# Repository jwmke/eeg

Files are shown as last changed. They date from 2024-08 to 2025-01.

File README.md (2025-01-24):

# Open-Source Affordable EEG PCB

### An 8-channel EEG Pi Pico W shield, based off of OpenBCI's [Cyton Biosensing Board](https://shop.openbci.com/products/cyton-biosensing-board-8-channel), for 1/10th the price.



The heart of this PCB is a Texas Instrument's [ADS1299](https://www.ti.com/product/ADS1299), a low noise, 8-Channel, Analog-to-Digital Converter.

## Instructions
1. Update your SSID and PASSWORD in the pico/main.py file
2. Upload the main.py to the Pi Pico W
3. Run the pico/main.py on the Pico Pi W and note the printed IP
5. Unplug the Pi Pico W from the PC and place it into the PCB
6. Update the PICO_IP in the computer/plot_data.py file
7. Run the computer/plot_data.py on a PC
8. Plug a 3.7V Lipo battery into the PCB
9. Blinking LED == Connecting, Solid LED == Succesfully streaming to PC

## Schematics





















## Layout

Top



Bottom



Ground



AVSS/-2.5V



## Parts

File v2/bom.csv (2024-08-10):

Id | Designator | Footprint | Quantity | Designation | Supplier and ref
1 | C22,C19,C18,C3 | C_0603_1608Metric_Pad1.08x0.95mm_HandSolder | 4 | 10µF
2 | R9,R7,R8,R3,R10,R6,R2 | R_0603_1608Metric_Pad0.98x0.95mm_HandSolder | 7 | 10kΩ
3 | U11 | 73225 | 1 | TPS73225DBVR
4 | U9,U4,U3 | tpd4e1b06dckr | 3 | TPD4E1B06DCKR
5 | U8 | 72325 | 1 | TPS72325DBVT
6 | U7 | 73233 | 1 | TPS73233DBVT
7 | U6 | SOTFL50P160X60-6N | 1 | TPS61023DRLR
8 | U5 | lm266 | 1 | LM2664M6
9 | RN8,RN7,RN6,RN5 | RES-ARRAY-SMD_0603-8P-L3.2-W1.6-BL | 4 | CAY16-103J4LF
10 | R5 | R_0603_1608Metric_Pad0.98x0.95mm_HandSolder | 1 | 100kΩ
11 | R4 | R_0603_1608Metric_Pad0.98x0.95mm_HandSolder | 1 | 732kΩ
12 | R1 | R_0603_1608Metric_Pad0.98x0.95mm_HandSolder | 1 | 1MΩ
13 | L1 | IND_74438357010_WRE | 1 | 1µH
14 | J1 | JST_PH_B2B-PH-K_1x02_P2.00mm_Vertical | 1 | Conn_01x02_Pin
15 | C30,C28,C23 | C_0603_1608Metric_Pad1.08x0.95mm_HandSolder | 3 | 0.01µF
16 | C29,C27,C17,C14,C10,C4,C12,C5,C9 | C_0603_1608Metric_Pad1.08x0.95mm_HandSolder | 9 | 1µF
17 | C24,C21,C20 | C_0603_1608Metric_Pad1.08x0.95mm_HandSolder | 3 | 22µF
18 | C16,C15,C11,C6,C2,C8 | C_0603_1608Metric_Pad1.08x0.95mm_HandSolder | 6 | 0.1µF
19 | C7 | C_0603_1608Metric_Pad1.08x0.95mm_HandSolder | 1 | 1nF
20 | C1 | C_0603_1608Metric_Pad1.08x0.95mm_HandSolder | 1 | 1.5nF
21 | CN4,CN3,CN2,CN1 | CAP-ARRAY-SMD_6124-8P-L3.2-W1.6-BL | 4 | W2A41C681KAT2A
22 | J3,J4 | PinSocket_1x20_P2.54mm_Vertical | 2 | Conn_01x20_Socket
23 | J2 | PinHeader_1x09_P2.54mm_Vertical | 1 | Conn_01x09_Pin
24 | U1 | PAG64_TEX | 1 | ADS1299IPAGR
25 | C13 | C_1206_3216Metric_Pad1.33x1.80mm_HandSolder | 1 | 100µF

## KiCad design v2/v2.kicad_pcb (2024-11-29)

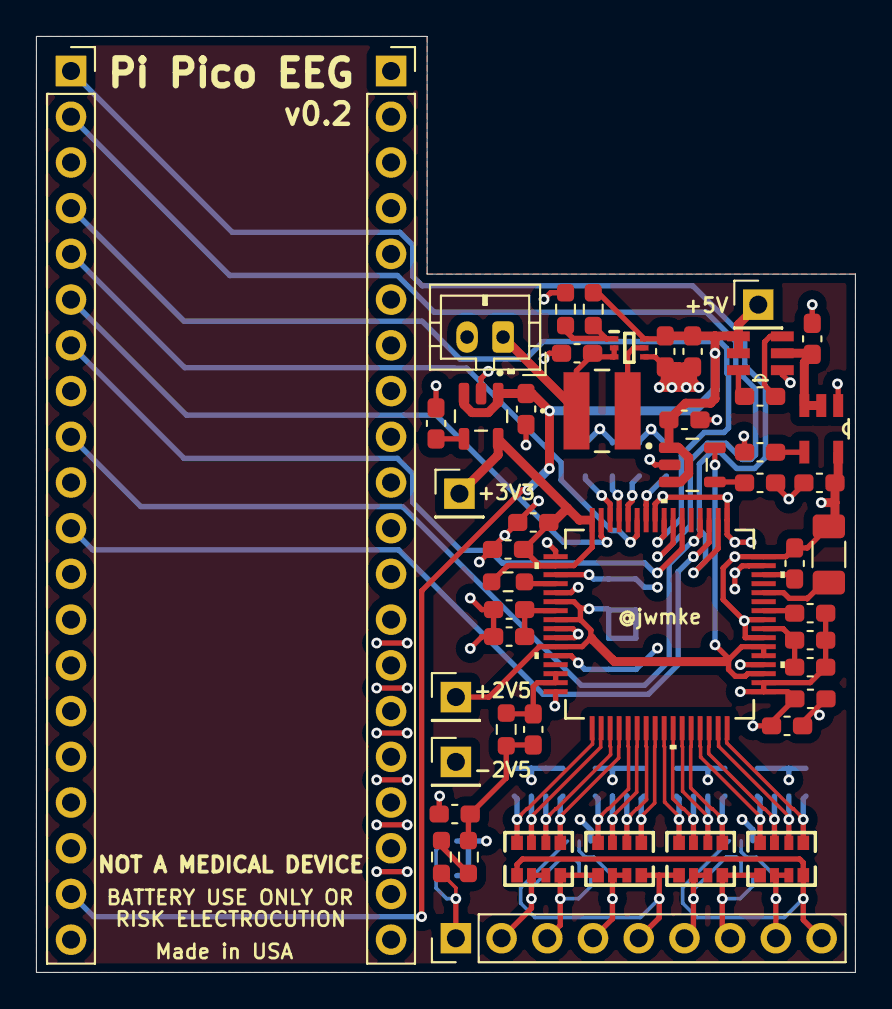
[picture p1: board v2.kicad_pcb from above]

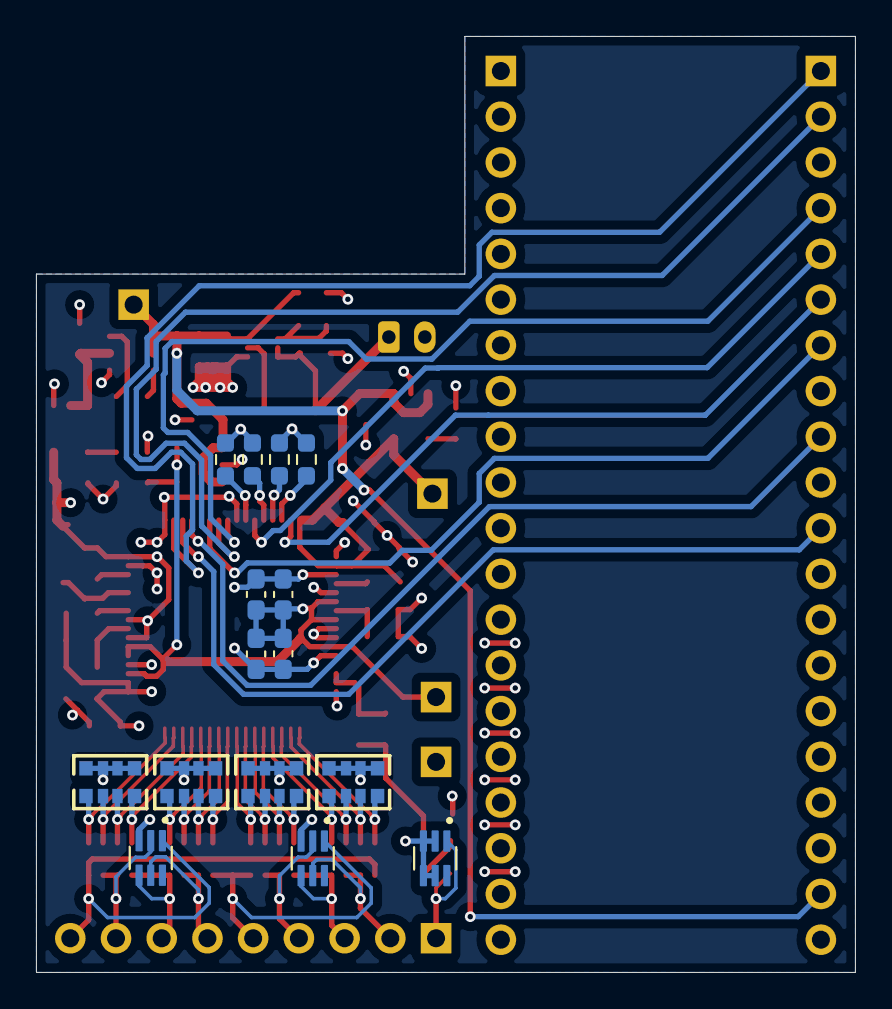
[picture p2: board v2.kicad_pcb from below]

Board: 4 copper layers, 45.5 x 52.0 mm, 64 parts (15 on the bottom side), 60 nets.

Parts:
C1: 1.5nF; C_0603_1608Metric_Pad1.08x0.95mm_HandSolder
C2, C6, C8, C11, C15, C16: 0.1µF; C_0603_1608Metric_Pad1.08x0.95mm_HandSolder
C3, C18, C19, C22: 10µF; C_0603_1608Metric_Pad1.08x0.95mm_HandSolder
C4, C5, C9, C10, C12, C14, C17, C27, C29: 1µF; C_0603_1608Metric_Pad1.08x0.95mm_HandSolder
C7: 1nF; C_0603_1608Metric_Pad1.08x0.95mm_HandSolder
C13: 100µF; C_1206_3216Metric_Pad1.33x1.80mm_HandSolder
C20, C21, C24: 22µF; C_0603_1608Metric_Pad1.08x0.95mm_HandSolder
C23, C28, C30: 0.01µF; C_0603_1608Metric_Pad1.08x0.95mm_HandSolder
CN1, CN2, CN3, CN4: W2A41C681KAT2A; CAP-ARRAY-SMD_6124-8P-L3.2-W1.6-BL
J1: Conn_01x02_Pin; JST_PH_B2B-PH-K_1x02_P2.00mm_Vertical
J2: Conn_01x09_Pin; PinHeader_1x09_P2.54mm_Vertical
J3, J4: Conn_01x20_Socket; PinSocket_1x20_P2.54mm_Vertical
J5, J6, J7, J8: Conn_01x01_Pin; PinHeader_1x01_P2.54mm_Vertical
L1: 1µH; IND_74438357010_WRE
R1: 1MΩ; R_0603_1608Metric_Pad0.98x0.95mm_HandSolder
R2, R3, R6, R7, R8, R9, R10: 10kΩ; R_0603_1608Metric_Pad0.98x0.95mm_HandSolder
R4: 732kΩ; R_0603_1608Metric_Pad0.98x0.95mm_HandSolder
R5: 100kΩ; R_0603_1608Metric_Pad0.98x0.95mm_HandSolder
RN5, RN6, RN7, RN8: CAY16-103J4LF; RES-ARRAY-SMD_0603-8P-L3.2-W1.6-BL
U1: ADS1299IPAGR; PAG64_TEX
U3, U4, U9: TPD4E1B06DCKR; tpd4e1b06dckr
U5: LM2664M6; lm266
U6: TPS61023DRLR; SOTFL50P160X60-6N
U7: TPS73233DBVT; 73233
U8: TPS72325DBVT; 72325
U11: TPS73225DBVR; 73225

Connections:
+2V5: C4.1, C6.1, C10.1, C11.1, J8.1, U1.19 (AVDD), U1.21 (AVDD), U1.22 (AVDD), U1.54 (AVDD1), U1.56 (AVDD), U1.59 (AVDD), U11.5 (OUT)
+3V3: C16.1, C17.1, J7.1, R6.1, U1.48 (DVDD), U1.50 (DVDD), U7.5 (OUT)
+5V: C20.2, C21.2, C27.2, C29.2, J3.19, J5.1, R4.1, U5.4 (~SD), U5.5 (V+), U6.6 (VOUT), U7.1 (IN), U7.3 (EN), U11.1 (IN), U11.3 (EN)
-2V5: C2.1, C3.2, C5.2, C8.1, C9.1, C10.2, C11.2, C12.2, C13.2, C14.1, C15.1, C24.2, J6.1, U1.17 (SRB1), U1.18 (SRB2), U1.20 (AVSS), U1.23 (AVSS), U1.25 (VREFN), U1.32 (AVSS), U1.53 (AVSS1), U1.57 (AVSS), U1.58 (AVSS), U1.60 (BIASREF), U8.5 (OUT)
-5V: C22.2, U5.2 (OUT), U8.2 (IN), U8.3 (EN)
/ADS1299/BI: J2.1, R2.2, U9.1 (IO1)
/ADS1299/Bias: C1.2, C7.1, R1.2, R10.1
/ADS1299/CS: J3.2, U1.39 (*CS)
/ADS1299/DRDY: J3.6, U1.47 (*DRDY)
/ADS1299/I1: J2.9, RN5.1, RN8.4, U3.1 (IO1)
/ADS1299/I2: J2.8, RN8.2, RN8.3, U3.2 (IO2)
/ADS1299/I3: J2.7, RN7.4, RN8.1, U3.4 (IO3)
/ADS1299/I4: J2.6, RN7.2, RN7.3, U3.5 (IO4)
/ADS1299/I5: J2.5, RN6.4, RN7.1, U4.1 (IO1)
/ADS1299/I6: J2.4, RN6.2, RN6.3, U4.2 (IO2)
/ADS1299/I7: J2.3, RN5.4, RN6.1, U4.4 (IO3)
/ADS1299/I8: J2.2, RN5.2, RN5.3, U4.5 (IO4)
/ADS1299/IN1N: CN1.2, RN8.6, U1.15 (IN1N)
/ADS1299/IN1P: CN1.1, RN8.5, U1.16 (IN1P)
/ADS1299/IN2N: CN1.4, RN8.8, U1.13 (IN2N)
/ADS1299/IN2P: CN1.3, RN8.7, U1.14 (IN2P)
/ADS1299/IN3N: CN2.2, RN7.6, U1.11 (IN3N)
/ADS1299/IN3P: CN2.1, RN7.5, U1.12 (IN3P)
/ADS1299/IN4N: CN2.4, RN7.8, U1.9 (IN4N)
/ADS1299/IN4P: CN2.3, RN7.7, U1.10 (IN4P)
/ADS1299/IN5N: CN3.2, RN6.6, U1.7 (IN5N)
/ADS1299/IN5P: CN3.1, RN6.5, U1.8 (IN5P)
/ADS1299/IN6N: CN3.4, RN6.8, U1.5 (IN6N)
/ADS1299/IN6P: CN3.3, RN6.7, U1.6 (IN6P)
/ADS1299/IN7N: CN4.2, RN5.6, U1.3 (IN7N)
/ADS1299/IN7P: CN4.1, RN5.5, U1.4 (IN7P)
/ADS1299/IN8N: CN4.4, RN5.8, U1.1 (IN8N)
/ADS1299/IN8P: CN4.3, RN5.7, U1.2 (IN8P)
/ADS1299/MISO: J3.5, U1.43 (DOUT)
/ADS1299/MOSI: J3.1, U1.34 (DIN)
/ADS1299/PDWN: J3.11, U1.35 (*PWDN)
/ADS1299/RESET: J3.9, U1.36 (*RESET)
/ADS1299/SCLK: J3.4, U1.40 (SCLK)
/ADS1299/START: J3.7, U1.38 (START)
/Booster/VBATT: C19.1, J1.1, L1.1, U6.2 (EN), U6.3 (VIN)
GND: C4.2, C6.2, C7.2, C14.2, C15.2, C16.2, C17.2, C19.2, C20.1, C21.1, C22.1, C23.1, C24.1, C27.1, C28.1, C29.1, C30.1, CN1.5, CN1.6, CN1.7, CN1.8, CN2.5, CN2.6, CN2.7, CN2.8, CN3.5, CN3.6, CN3.7, CN3.8, CN4.5, CN4.6, CN4.7, CN4.8, J1.2, J3.18, R3.2, R5.2, R7.2, R8.2, R9.2, U1.31 (RESV1), U1.33 (DGND), U1.41 (DAISY_IN), U1.49 (DGND), U1.51 (DGND), U1.64 (RESERVED), U3.3 (GND), U4.3 (GND), U5.1 (GND), U6.4 (GND), U7.2 (GND), U8.1 (GND), U9.2 (IO2), U9.3 (GND), U9.4 (IO3), U9.5 (IO4), U11.2 (GND)
unnamed: R2.1, R10.2
unnamed: C1.1, R1.1, U1.62 (BIASIN), U1.63 (BIASOUT)
unnamed: R6.2, U1.52 (CLKSEL)
unnamed: R3.1, U1.42 (GPIO1)
unnamed: R7.1, U1.44 (GPIO2)
unnamed: R8.1, U1.45 (GPIO3)
unnamed: R9.1, U1.46 (GPIO4)
unnamed: C13.1, U1.28 (VCAP1)
unnamed: C12.1, U1.30 (VCAP2)
unnamed: C8.2, C9.2, U1.55 (VCAP3)
unnamed: C5.1, U1.26 (VCAP4)
unnamed: C2.2, C3.1, U1.24 (VREFP)
unnamed: C18.1, U5.6 (CAP+)
unnamed: C18.2, U5.3 (CAP-)
unnamed: R4.2, R5.1, U6.1 (FB)
unnamed: L1.2, U6.5 (SW)
unnamed: C28.2, U7.4 (NR/FB)
unnamed: C23.2, U8.4 (NR)
unnamed: C30.2, U11.4 (NR/FB)

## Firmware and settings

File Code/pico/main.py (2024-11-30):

import network
import socket
from machine import Pin, SPI
import time
import json

# WiFi credentials
SSID = ''
PASSWORD = ''

# Setup LED
try:
    led = Pin("LED", Pin.OUT)
except:
    led = Pin(25, Pin.OUT)

def blink_led():
    """Toggle LED state"""
    led.toggle()

def set_led_on():
    """Turn LED on solid"""
    led.value(1)

def set_led_off():
    """Turn LED off"""
    led.value(0)

def connect_wifi():
    """Connect to WiFi"""
    wlan = network.WLAN(network.STA_IF)
    wlan.active(True)
    wlan.connect(SSID, PASSWORD)
    
    # Wait for connection, blinking LED while trying
    max_wait = 10
    while max_wait > 0:
        if wlan.status() < 0 or wlan.status() >= 3:
            break
        max_wait -= 1
        print('Waiting for connection...')
        blink_led()
        time.sleep(0.5)
        blink_led()
        time.sleep(0.5)
    
    if wlan.status() != 3:
        # Connection failed - keep LED blinking
        raise RuntimeError('WiFi connection failed')
    else:
        # Connection successful - LED solid
        set_led_on()
        print('Connected')
        status = wlan.ifconfig()
        print('IP:', status[0])
    return status[0]  # Return IP address

class SoftSPI:
    def __init__(self, sck, mosi, miso, baudrate=1000000):
        self.sck = sck
        self.sck.init(Pin.OUT, value=0)
        
        self.mosi = mosi
        self.mosi.init(Pin.OUT, value=0)
        
        self.miso = miso
        self.miso.init(Pin.IN)
        
        # SPI Mode 1: CPOL=0, CPHA=1
        self.sck.value(0)  # Ensure clock starts low

    def write(self, data):
        for b in data:
            # Delay before byte transmission
            time.sleep_us(10)
            
            for i in range(8):
                self.mosi.value((b >> (7-i)) & 1)  # Set data
                time.sleep_us(5)  # Setup time
                self.sck.value(1)  # Clock high
                time.sleep_us(5)  # Hold time
                self.sck.value(0)  # Clock low
                time.sleep_us(5)  # Inter-bit delay
            
            # Inter-byte delay
            time.sleep_us(10)

    def readinto(self, buf):
        for i in range(len(buf)):
            byte = 0
            # Delay before byte reception
            time.sleep_us(10)
            
            for j in range(8):
                self.sck.value(1)  # Clock high
                time.sleep_us(5)   # Setup time
                bit = self.miso.value()
                byte = (byte << 1) | bit
                time.sleep_us(5)   # Hold time
                self.sck.value(0)  # Clock low
                time.sleep_us(5)   # Inter-bit delay
            
            buf[i] = byte
            # Inter-byte delay
            time.sleep_us(10)

class ADS1299:
    def __init__(self):
        # GPIO setup with forced output mode
        self.cs = Pin(2, Pin.OUT)    
        self.cs.on()  # Set high (inactive)
        
        self.start = Pin(7, Pin.OUT)
        self.start.off()  # Start low
        
        self.reset = Pin(9, Pin.OUT)
        self.reset.on()   # Start high
        
        self.pwdn = Pin(11, Pin.OUT)
        self.pwdn.on()    # Start high (powered on)
        
        self.drdy = Pin(6, Pin.IN)   # DRDY as input

        # Setup SPI pins with forced values
        self.sck = Pin(4, Pin.OUT)
        self.mosi = Pin(1, Pin.OUT)
        self.miso = Pin(5, Pin.IN)
        
        # Force initial states
        self.sck.off()    # Clock starts low
        self.mosi.off()   # MOSI starts low
        
        # Initialize Software SPI
        self.spi = SoftSPI(sck=self.sck, mosi=self.mosi, miso=self.miso)

            
    def write_reg(self, reg, data):
        """Write data to a register"""
        print(f"Writing register {hex(reg)} with value {hex(data)}")
        self.cs.value(1)
        time.sleep_ms(1)  # Longer delay
        self.cs.value(0)
        time.sleep_ms(1)  # Longer delay
        
        # Send write command
        self.spi.write(bytes([0x40 | reg]))
        time.sleep_ms(1)  # Longer delay
        
        # Send number of registers to write minus 1
        self.spi.write(bytes([0x00]))
        time.sleep_ms(1)  # Longer delay
        
        # Send data
        self.spi.write(bytes([data]))
        time.sleep_ms(1)  # Longer delay
        
        self.cs.value(1)
        time.sleep_ms(1)  # Longer delay

    def read_reg(self, reg):
        """Read from a register"""
        self.cs.value(1)  # Ensure CS is high initially
        time.sleep_us(2)
        self.cs.value(0)  # Pull CS low to start transaction
        time.sleep_us(2)
        self.spi.write(bytes([0x20 | reg]))  # Read command
        time.sleep_us(2)
        self.spi.write(bytes([0x00]))        # Number of registers to read
        time.sleep_us(2)
        result = bytearray(1)
        self.spi.readinto(result)
        time.sleep_us(2)
        self.cs.value(1)  # Pull CS high to end transaction
        time.sleep_us(2)
        return result[0]

    def send_command(self, cmd):
        """Send a command to ADS1299"""
        self.cs.value(1)  # Ensure CS is high initially
        time.sleep_us(2)
        self.cs.value(0)  # Pull CS low to start transaction
        time.sleep_us(2)
        self.spi.write(bytes([cmd]))
        time.sleep_us(2)
        self.cs.value(1)  # Pull CS high to end transaction
        time.sleep_us(2)
    
    def verify_communication(self):
        """Verify SPI communication"""
        print("Verifying SPI communication...")
        
        # Write a test pattern to CONFIG2 register
        test_value = 0xD0  # A value we haven't used yet
        print(f"Writing test value {hex(test_value)} to CONFIG2")
        self.write_reg(0x02, test_value)
        
        # Read back the value
        time.sleep_ms(10)
        readback = self.read_reg(0x02)
        print(f"Read back value: {hex(readback)}")
        
        if readback == test_value:
            print("SPI communication verified!")
            return True
        else:
            print("SPI communication failed!")
            return False

    def init_device(self):
        """Initialize the ADS1299"""
        print("Starting device initialization...")
        
        # Power up sequence
        print("Power down")
        self.pwdn.value(0)
        time.sleep_ms(100)
        print("Power up")
        self.pwdn.value(1)
        time.sleep_ms(100)
        
        # Reset sequence
        print("Start reset sequence")
        self.reset.value(1)
        time.sleep_ms(100)
        print("Reset low")
        self.reset.value(0)
        time.sleep_ms(100)
        print("Reset high")
        self.reset.value(1)
        time.sleep_ms(100)
        
        # Send SDATAC command
        print("Sending SDATAC command")
        self.send_command(0x11)
        time.sleep_ms(10)
        
        # Verify communication
        if not self.verify_communication():
            raise RuntimeError("Failed to establish SPI communication")
        
    def start_acquisition(self, sock):
        """Start continuous data acquisition and send over WiFi"""
        self.send_command(0x10)  # RDATAC
        self.start.value(1)
        
        try:
            while True:
                data = self.read_data_sample()
                # Convert data to JSON string
                data_json = json.dumps({'channels': data})
                sock.send(data_json.encode() + b'\n')
                time.sleep_ms(4)  # Maintain ~250 SPS
                
        except Exception as e:
            print(f"Error: {e}")
            self.start.value(0)
            self.send_command(0x11)  # SDATAC
            # If connection is lost, start blinking LED
            while True:
                blink_led()
                time.sleep(0.5)
    
    def read_data_sample(self):
        """Read one sample from all channels"""
        while self.drdy.value():
            pass
            
        self.cs.value(0)
        
        # Read 27 bytes (status + 8 channels)
        raw_data = bytearray(27)
        self.spi.readinto(raw_data)
        
        self.cs.value(1)
        
        # Parse the data
        channels_data = []
        for i in range(8):
            start_idx = 3 + (i * 3)
            channel_data = (raw_data[start_idx] << 16) | (raw_data[start_idx + 1] << 8) | raw_data[start_idx + 2]
            
            # Debug print raw bytes
            print(f"Ch{i+1} raw bytes: {hex(raw_data[start_idx])} {hex(raw_data[start_idx + 1])} {hex(raw_data[start_idx + 2])}")
            
            # Convert to signed value
            if channel_data & 0x800000:
                channel_data |= ~0xFFFFFF
            
            # Debug print before voltage conversion
            print(f"Ch{i+1} value before conversion: {channel_data}")
            
            # Convert to microvolts
            voltage = (channel_data * 4.5 * 1000000) / (24 * 8388607)
            print(f"Ch{i+1} voltage: {voltage} µV")
            channels_data.append(voltage)
        
        #print("Raw channel data:", channels_data)  # Debug print
        return channels_data

# Main execution
def main():
    try:
        # Start with LED blinking
        set_led_off()
        
        # Connect to WiFi
        ip = connect_wifi()
        
        # Setup Socket Server
        addr = socket.getaddrinfo('0.0.0.0', 80)[0][-1]
        s = socket.socket()
        s.bind(addr)
        s.listen(1)
        
        print('Ready for connection')
        
        # Initialize ADS1299
        ads = ADS1299()
        ads.init_device()
        
        while True:
            cl, addr = s.accept()
            print('Client connected from', addr)
            set_led_on()  # Solid LED when client connected
            ads.start_acquisition(cl)
            cl.close()
            # If we get here, connection was lost
            set_led_off()
            
    except KeyboardInterrupt:
        set_led_off()
    except Exception as e:
        print(f"Error: {e}")
        # Error occurred, blink LED continuously
        while True:
            blink_led()
            time.sleep(0.5)

if __name__ == '__main__':
    main()

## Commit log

2024-07-11 kicad project init
    [PCBs.kicad_pcb, PCBs.kicad_sch]
2024-07-11 import ads1299
    [PCBs.kicad_sch]
2024-07-12 adding vcaps
    [PCBs.kicad_sch]
2024-07-13 moving vcaps
    [PCBs.kicad_sch]
2024-07-14 esp32 to pi pico
    [PCBs.kicad_sch]
2024-07-14 vref pins
    [PCBs.kicad_sch]
2024-07-15 ads1299 symbol planning
    [PCBs.kicad_sch]
2024-07-16 ads1299 final symbol plan
    [PCBs.kicad_sch]
2024-07-17 adding back INxN channels
    [PCBs.kicad_sch]
2024-07-17 avss avdd connections
    [PCBs.kicad_sch]
2024-07-17 dvdd clk and clksel
    [PCBs.kicad_sch]
2024-07-18 first input schem draft
    [PCBs.kicad_sch]
2024-07-19 input cp
    [PCBs.kicad_sch]
2024-07-20 input offset montage
    [PCBs.kicad_sch]
2024-07-20 duplicate input
    [PCBs.kicad_sch]
2024-07-20 bias input draft
    [PCBs.kicad_sch]
2024-07-20 volt regs
    [PCBs.kicad_sch]
2024-07-21 booster and voltage regulators
    [PCBs.kicad_sch]
2024-07-22 v0.1 schematic finishing touches
    [PCBs.kicad_sch]
2024-07-22 removed old input schem
    [PCBs.kicad_sch]
2024-07-23 avss adjustments
    [PCBs.kicad_sch]
2024-07-23 ground unused gpio
    [PCBs.kicad_sch]
2024-07-24 simplifying inputs
    [PCBs.kicad_sch]
2024-07-27 power on own sheet
    [PCBs.kicad_sch, power.kicad_sch]
2024-07-27 volt reg to power page
    [PCBs.kicad_sch, power.kicad_sch]
2024-07-29 other pages for volt regs
    [5Vto-2V5.kicad_sch, 5Vto-5V.kicad_sch, 5Vto2V5.kicad_sch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]
2024-07-29 connecting volt regs
    [5Vto-2V5.kicad_sch, 5Vto-5V.kicad_sch, 5Vto2V5.kicad_sch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]
2024-07-29 RP2040 sheet
    [5Vto-2V5.kicad_sch, 5Vto-5V.kicad_sch, 5Vto2V5.kicad_sch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]
2024-07-29 ads1299 sheet
    [5Vto-2V5.kicad_sch, 5Vto-5V.kicad_sch, 5Vto2V5.kicad_sch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]
2024-07-29 root page org
    [5Vto-2V5.kicad_sch, 5Vto-5V.kicad_sch, 5Vto2V5.kicad_sch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]
2024-07-30 ads1299 layout change
    [5Vto-2V5.kicad_sch, 5Vto-5V.kicad_sch, 5Vto2V5.kicad_sch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]
2024-07-31 start of footprints
    [5Vto-2V5.kicad_sch, 5Vto-5V.kicad_sch, 5Vto2V5.kicad_sch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]
2024-07-31 more footprints
    [5Vto-2V5.kicad_sch, 5Vto-5V.kicad_sch, 5Vto2V5.kicad_sch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]
2024-07-31 cap footprints finished
    [5Vto-2V5.kicad_sch, 5Vto-5V.kicad_sch, 5Vto2V5.kicad_sch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]
2024-07-31 cap and resis array footprints
    [5Vto-2V5.kicad_sch, 5Vto-5V.kicad_sch, 5Vto2V5.kicad_sch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]
2024-08-01 res footprints
    [5Vto-2V5.kicad_sch, 5Vto-5V.kicad_sch, 5Vto2V5.kicad_sch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]
2024-08-01 final footprints
    [5Vto-2V5.kicad_sch, 5Vto-5V.kicad_sch, 5Vto2V5.kicad_sch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]
2024-08-01 initial pcb import
    [5Vto-2V5.kicad_sch, 5Vto-5V.kicad_sch, 5Vto2V5.kicad_sch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]
2024-08-01 pi socket spacing
    [5Vto-2V5.kicad_sch, 5Vto-5V.kicad_sch, 5Vto2V5.kicad_sch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]
2024-08-01 begining traces
    [PCBs.kicad_pcb]
2024-08-02 v0.1, pre-grounding
    [5Vto-2V5.kicad_sch, 5Vto-5V.kicad_sch, 5Vto2V5.kicad_sch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]
2024-08-03 layout additions
    [PCBs.kicad_pcb]
2024-08-06 v2 template
    [5Vto-2V5.kicad_sch, 5Vto-5V.kicad_sch, 5Vto2V5.kicad_sch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]
2024-08-07 fix bias
    [ADS1299.kicad_sch, v2.kicad_sch]
2024-08-08 footprint reset for v0.2
    [5Vto-2V5.kicad_sch, 5Vto-5V.kicad_sch, 5Vto2V5.kicad_sch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]
2024-08-08 new footprints
    [5Vto-2V5.kicad_sch, 5Vto-5V.kicad_sch, 5Vto2V5.kicad_sch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]
2024-08-08 v02 init placements
    [v2.kicad_pcb]
2024-08-09 v2 volt regs and grounding
    [ADS1299.kicad_sch, v2.kicad_pcb]
2024-08-10 layout reorg
    [bom.csv]
2024-08-10 test pins
    [ADS1299.kicad_sch, v2.kicad_pcb, v2.kicad_sch]
2024-08-12 final v02
    [v2-B_Cu.gbl, v2-B_Mask.gbs, v2-B_Paste.gbp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]
2024-11-26 v2 code
    [5Vto-2V5.kicad_sch, 5Vto-5V.kicad_sch, 5Vto2V5.kicad_sch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]
2024-11-26 kicad deletions
2024-11-29 blink test
    [v2.kicad_pcb]
